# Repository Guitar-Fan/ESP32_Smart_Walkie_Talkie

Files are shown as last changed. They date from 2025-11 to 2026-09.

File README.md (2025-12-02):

# ESP32_Smart_Walkie_Talkie

This is a smart walkie talkie using an ESP32 development board. It functions as a walkie talkie. It uses a LoRa module to send radio signals 1 km+, and has smart features such as a low battery alert and a RSSI Signal Bar. The device features a custom-designed 3D-printed enclosure (made out of brown ABS filament) that houses all the electronics and provides a professional, handheld form factor.

I made this project to allow people to contact each other where cellular data wasn't an option. It would be especially helpful in a remote environment such as a forest, to talk with somebody, or broadcast your signal in case of emergencies. I wanted my first Blueprint project to be useful to the everyday public.

## Images

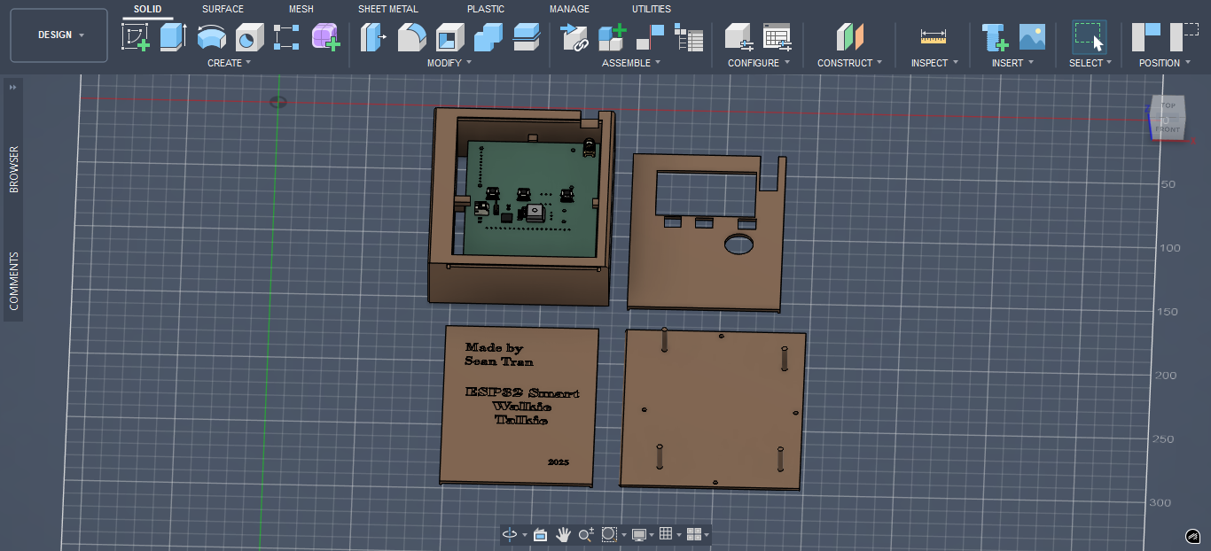
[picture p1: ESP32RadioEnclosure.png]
Enclosure View


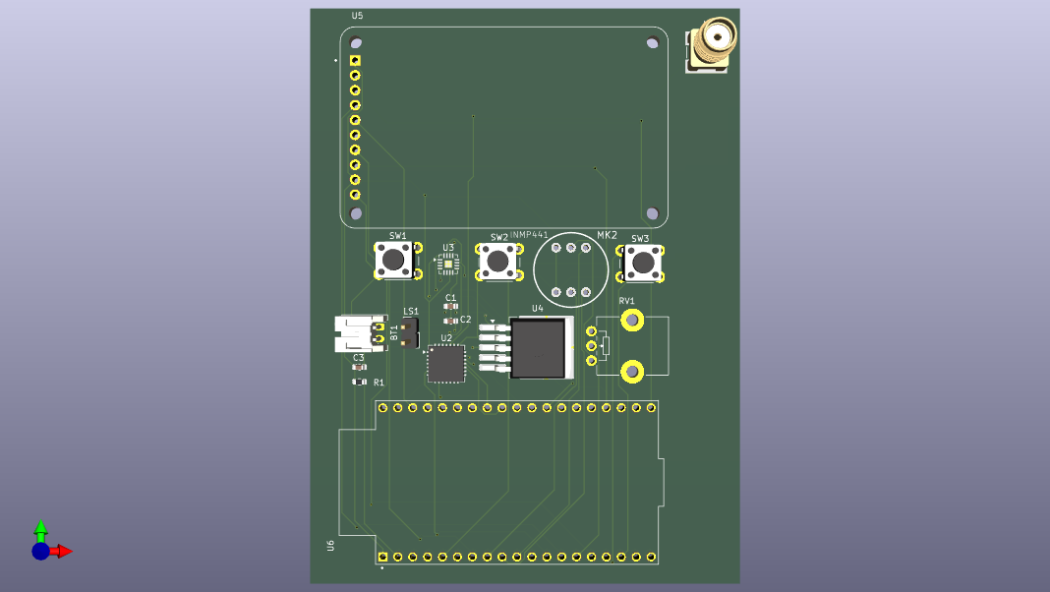
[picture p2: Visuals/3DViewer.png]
3D Viewer


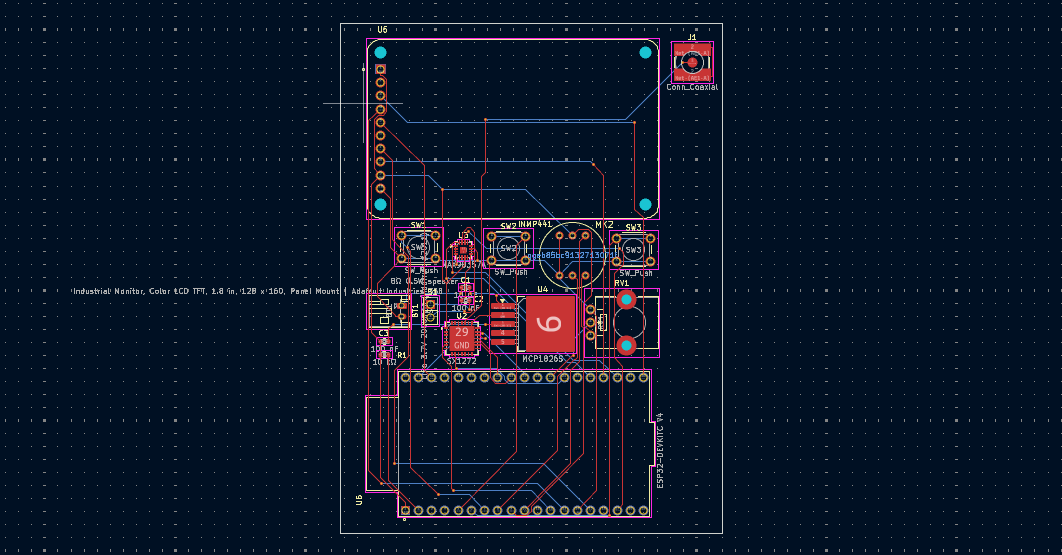
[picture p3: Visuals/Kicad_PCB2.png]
Kicad PCB


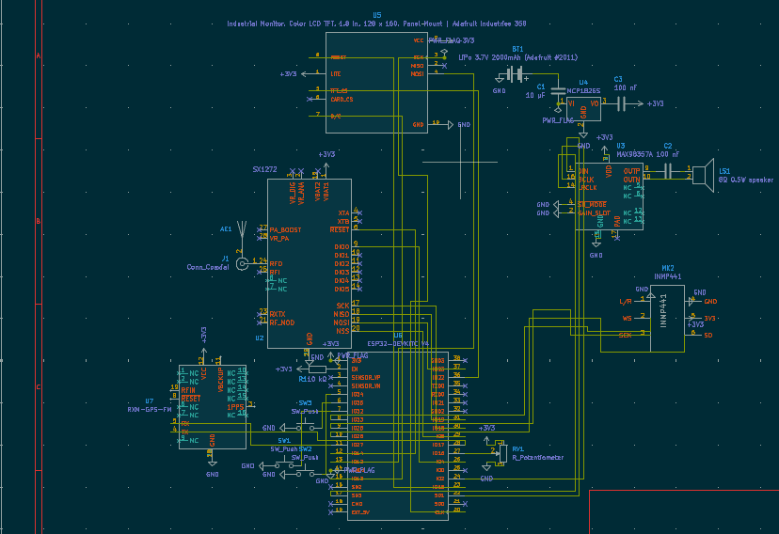
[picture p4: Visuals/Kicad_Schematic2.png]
Kicad Schematic


## Bill of Materials (BOM)

| Name | Qty | Description | Unit Price | Total Price | URL |
|---|-----|---|---|---|-----|
| 3.7V 103450 Polymer Lithium Battery, 2000 mAh Rechargeable | 2 | BATTERY LITH-ION 3.7V 2AH | $8.26 | $16.52 | [AliExpress](https://www.aliexpress.us/item/3256802548415679.html?gatewayAdapt=glo2usa4itemAdapt) |
| 1.8'' TFT Full Color LCD Display (2pcs) | 1 | TFT LCD display | $6.44 | $6.44 | [AliExpress](https://www.aliexpress.us/item/3256808787979678.html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) |
| Conn_Coaxial SMA KHD (5pcs) | 1 | Coaxial connector | $2.09 | $2.09 | [AliExpress](https://www.aliexpress.us/item/2255800008688086.html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) |
| MAX98357A | 2 | Audio amplifier | $1.93 | $3.86 | [AliExpress](https://www.aliexpress.us/item/3256805196806369.html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) |
| 3W 8 ohm 2W speaker | 2 | Audio output device | $2.03 | $4.06 | [AliExpress](https://www.aliexpress.us/item/3256805513567413.html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) |
| INMP441 | 2 | Omnidirectional microphone | $2.43 | $4.86 | [AliExpress](https://www.aliexpress.us/item/3256806131008765.html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) |
| ESP32-DEVKITC V4 | 2 | Microcontroller development board | $5.32 | $10.64 | [eBay](https://www.ebay.com/itm/376392617070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) |
| 915 MHz Meshtastic LoRa Antenna with RP or SMA Male 915MHz for LoRaWan Aerial | 2 | Antenna 915hz | $5.00 | $10.00 | [eBay](https://www.ebay.com/itm/154891841854) |
| [2-Pack] 3.7V USB Charger Cable SM-2P Plug Cable with LED Indicator | 1 | Recharging Unit for Battery | $3.98 | $3.98 | [Amazon](https://www.amazon.com/2-Pack-Charger-Indicator-Amphibious-Battery/dp/B0FF33J253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) |
| SX1272IMLTRT | 2 | LoRa transceiver module | $8.85 | $17.70 | [DigiKey](https://www.digikey.com/en/products/detail/semtech-corporation/SX1262IMLTRT/8564369) |
| JST_PH_S2B-PH-K_1x02_P2.00mm_Horizontal | 2 | Headers for 3.7v LiPo Batteries | $0.10 | $0.20 | [DigiKey](https://www.digikey.com/en/products/detail/jst-sales-america-inc/S2B-PH-K-S/926626) |
| MCP1826S-3302E/DB | 2 | Voltage regulator | $0.91 | $1.82 | [DigiKey](https://www.digikey.com/en/products/detail/microchip-technology/MCP1826S-3302E-DB/1635997) |
| R_Potentiometer 10K | 2 | Variable resistor | $0.89 | $1.78 | [DigiKey](https://www.digikey.com/en/products/detail/bourns-inc/PTV09A-4020F-B103/3534181) |
| PCB from PCBWay | 1 | PCB | $5.00 | $5.00 | - |
| KEMET CAP CER 0.1UF 50V X7R 0603 | 10 | 100 nF capacitors | $0.11 | $0.11 | [DigiKey](https://www.digikey.com/en/products/detail/kemet/C0603C104K5RACTU/1465594) |
| CAP CER 10UF 10V X5R 0603 (Samsung Electro-Mechanics) | 10 | 10 µF capacitors | $0.30 | $0.30 | [DigiKey](https://www.digikey.com/en/products/detail/samsung-electro-mechanics/CL10A106KP8NNNC/3886850) |
| YAGEO RES 10K OHM 1% 1/10W 0603 | 10 | 10k Resistor for pull-ups | $0.06 | $0.06 | [DigiKey](https://www.digikey.com/en/products/detail/yageo/RC0603FR-0710KL/726880) |
| CONN HEADER VERT 2POS 2.54MM | 2 | Speaker pin Header | $0.11 | $0.22 | [DigiKey](https://www.digikey.com/en/products/detail/samtec-inc/TSW-102-07-F-S/2685866) |
| SW_Push | 6 | Push button switch | Exclude | Exclude | Exclude |

Note: My build needs 2 of each component(s) to test

Note2: Capacitors and resistors cheaper to buy at 10 quantity than what needed

Total without Tax: $89.64  
Total Funding Needed: $111.42

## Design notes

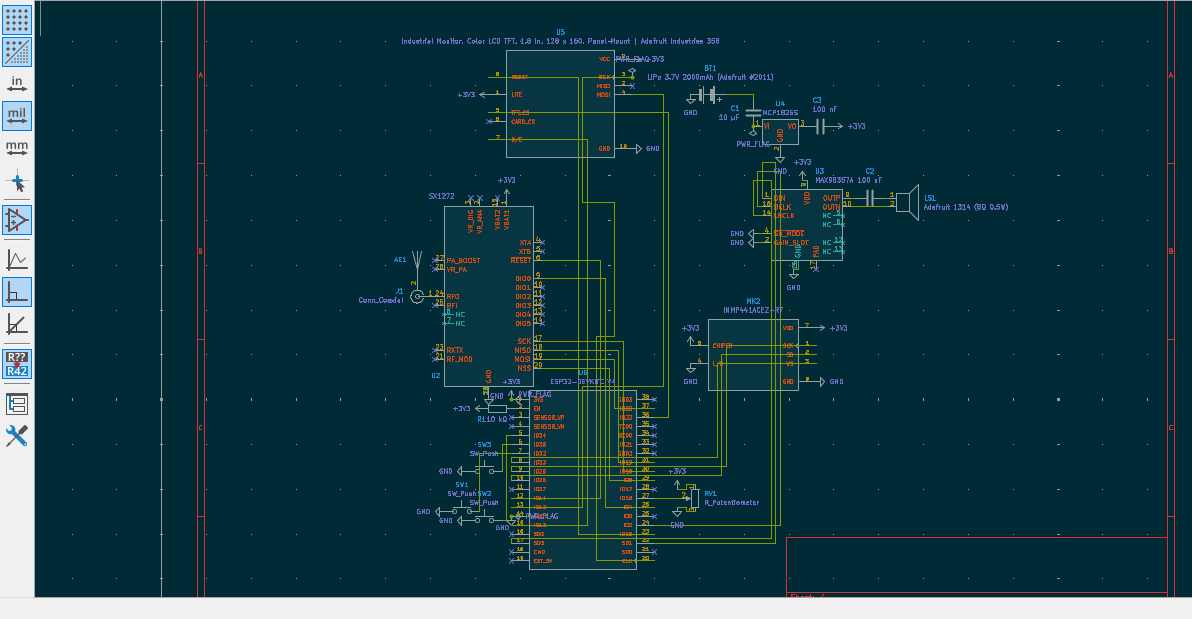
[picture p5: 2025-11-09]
Visuals/First_Draft/Kicad_Schematic.png

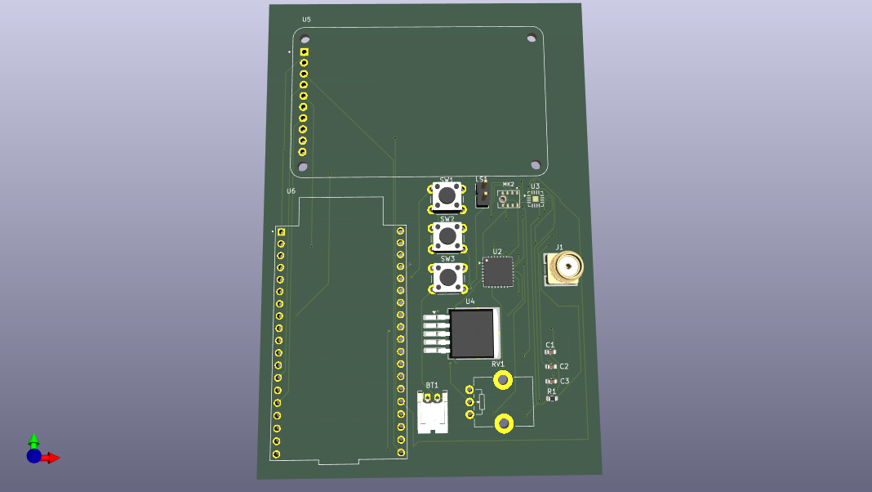
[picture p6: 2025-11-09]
Visuals/First_Draft/3DViewer_Kicad.png

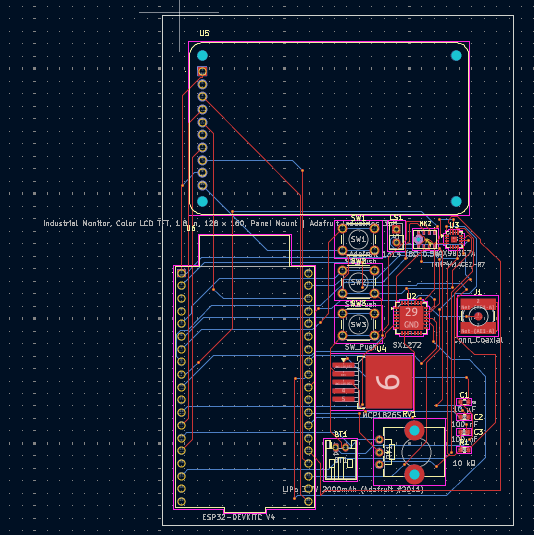
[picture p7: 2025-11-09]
Visuals/First_Draft/Kicad_PCB.png

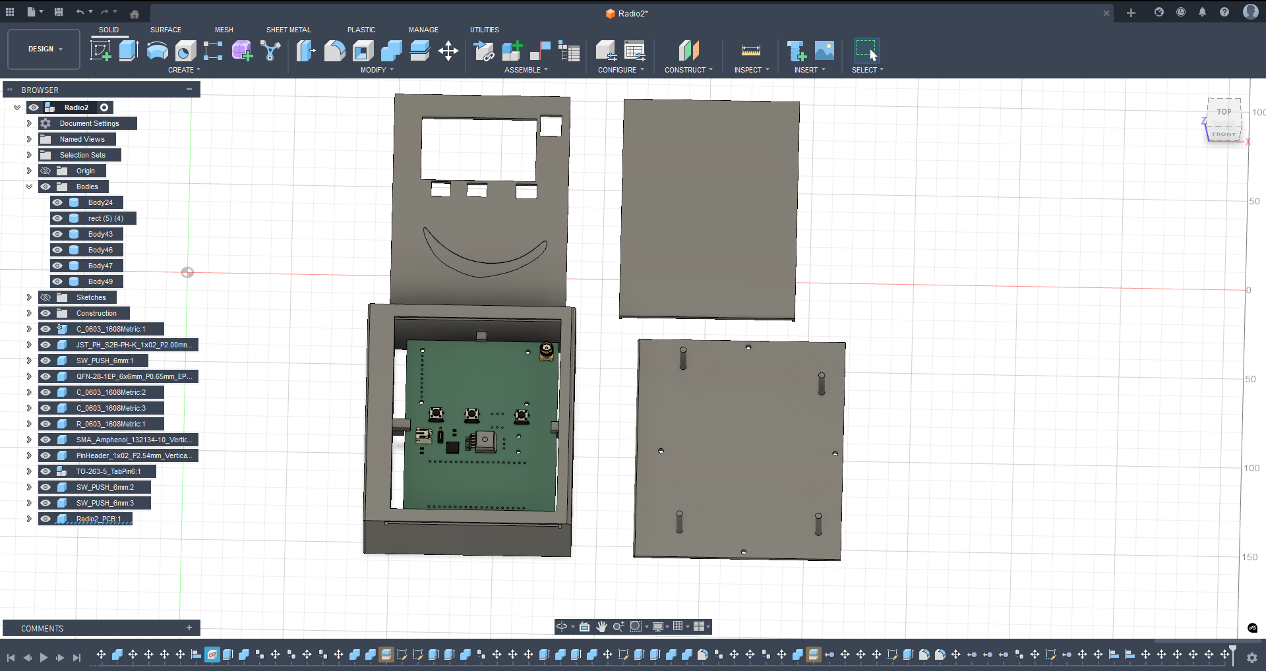
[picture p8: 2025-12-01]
Visuals/WalkieTalkieEnclosure_Fusion360.png

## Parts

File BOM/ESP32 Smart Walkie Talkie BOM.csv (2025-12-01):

Name | Qty | Description | Unit Price | Total Price | URL
3.7V 103450 Polymer Lithium Battery , 2000 mAh Rechargeable | 2 | BATTERY LITH-ION 3.7V 2AH | 8.26 | $16.52 | https://www.aliexpress.us/item/3256802548415679.html?gatewayAdapt=glo2usa4itemAdapt
1.8''tft Full Color Lcd Display (2pcs) | 1 | TFT LCD display | 6.44 | $6.44 | https://www.aliexpress.us/item/3256808787979678.html?curPageLogUid=IogOLCzfrTak
Conn_Coaxial SMA KHD (5pcs) | 1 | Coaxial connector | 2.09 | $2.09 | https://www.aliexpress.us/item/2255800008688086.html?curPageLogUid=HRgm0xYNEq4L |  | aliexpress: | 34.35
MAX98357A | 2 | Audio amplifier | $1.93 | $3.86 | https://www.aliexpress.us/item/3256805196806369.html?src=google |  | digikey: | 31.93
3w 8 ohm 2W speaker | 2 | Audio output device | 2.03 | $4.06 | https://www.aliexpress.us/item/3256805513567413.html?curPageLogUid=1UQMMRe9NU44 |  | Amazon: | 3.98
INMP441 | 2 | Omnidirectional microphone | 2.43 | $4.86 | https://www.aliexpress.us/item/3256806131008765.html?curPageLogUid=gpENJgXtYVrp |  | Ebay: | 33.8
ESP32-DEVKITC V4 | 2 | Microcontroller development board | $5.32 | $10.64 | https://www.ebay.com/itm/376392617070 |  | PCBWay: | $7.60
915 MHz Meshtastic LoRa Antenna with RP or SMA Male 915MHz for LoRaWan Aerial | 2 | Antenna 915hz | $5.00 | $10.00 | https://www.ebay.com/itm/154891841854 |  |  | 111.66
[2-Pack] 3.7V USB Charger Cable SM-2P Plug Cable with LED Indicator | 1 | Recharging Unit for Battery | 3.98 | $3.98 | https://www.amazon.com/2-Pack-Charger-Indicator-Amphibious-Battery/dp/B0FF33J253?rnid=386685011
SX1272IMLTRT | 2 | LoRa transceiver module | 8.85 | $17.70 | https://www.digikey.com/en/products/detail/semtech-corporation/SX1262IMLTRT/8564369
JST_PH_S2B-PH-K_1x02_P2.00mm_Horizontal | 2 | Headers for 3.7v LiPo Batteries | 0.1 | $0.20 | https://www.digikey.com/en/products/detail/jst-sales-america-inc/S2B-PH-K-S/926626
MCP1826S-3302E/DB | 2 | Voltage regulator | $0.91 | $1.82 | https://www.digikey.com/en/products/detail/microchip-technology/MCP1826S-3302E-DB/1635997
R_Potentiometer 10K | 2 | Variable resistor | 0.89 | $1.78 | https://www.digikey.com/en/products/detail/bourns-inc/PTV09A-4020F-B103/3534181
PCB from PCBWay | 1 | PCB | 5 | $5.00
KEMET CAP CER 0.1UF 50V X7R 0603 | 10 | 100 nF capacitors | 0.11 | $0.11 | https://www.digikey.com/en/products/detail/kemet/C0603C104K5RACTU/1465594
CAP CER 10UF 10V X5R 0603 (Samsung Electro-Mechanics) | 10 | 10 µF capacitors | $0.30 | $0.30 | https://www.digikey.com/en/products/detail/samsung-electro-mechanics/CL10A106KP8NNNC/3886850
YAGEO RES 10K OHM 1% 1/10W 0603 | 10 | 10k Resistor for pull-ups | $0.06 | $0.06 | https://www.digikey.com/en/products/detail/yageo/RC0603FR-0710KL/726880
CONN HEADER VERT 2POS 2.54MM | 2 | Speaker pin Header | 0.11 | $0.22 | https://www.digikey.com/en/products/detail/samtec-inc/TSW-102-07-F-S/2685866
SW_Push | 6 | Push button switch | Exclude | Exclude | Exclude
Note: My build needs 2 of each component(s) to test |  | Total without Tax: |  | $89.64 | Total Funding Needed: | $111.42
Note2: Capacitors and resistors cheaper to buy at 10 quantity than what needed

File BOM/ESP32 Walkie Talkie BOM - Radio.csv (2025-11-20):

Name | Qty | Description | Unit Price | Total Price | URL | Running Total
3.7V 103450 Polymer Lithium Battery , 2000 mAh Rechargeable | 1 | BATTERY LITH-ION 3.7V 2AH | 14 | $14.00 | https://www.aliexpress.us/item/3256802548415679.html?gatewayAdapt=glo2usa4itemAdapt | $20.29
1.8''tft Full Color Lcd Display (2pcs) | 1 | TFT LCD display | 6.44 | $6.44 | https://www.aliexpress.us/item/3256808787979678.html?curPageLogUid=IogOLCzfrTak | $8.53
Conn_Coaxial SMA KHD (5pcs) | 1 | Coaxial connector | 2.09 | $2.09 | https://www.aliexpress.us/item/2255800008688086.html?curPageLogUid=HRgm0xYNEq4L | 4.18 | aliexpress: | 38.92
MAX98357A | 2 | Audio amplifier | $1.93 | $3.86 | https://www.aliexpress.us/item/3256805196806369.html?src=google | 6.74 | digikey: | 31.83
3w 8 ohm 2W speaker | 2 | Audio output device | 2.03 | $4.06 | https://www.aliexpress.us/item/3256805513567413.html?curPageLogUid=1UQMMRe9NU44 | 6.56 | Amazon: | 12.12
INMP441 | 2 | Omnidirectional microphone | 2.43 | $4.86 | https://www.aliexpress.us/item/3256806131008765.html?curPageLogUid=gpENJgXtYVrp | 7.36 | Ebay: | 33.8
ESP32-DEVKITC V4 | 2 | Microcontroller development board | $5.32 | $10.64 | https://www.ebay.com/itm/376392617070 | 16.61 | PCBWay: | $7.60
915 MHz Meshtastic LoRa Antenna with RP or SMA Male 915MHz for LoRaWan Aerial | 2 | Antenna 915hz | $5.00 | $10.00 | https://www.ebay.com/itm/154891841854 | 15.15 |  | 124.27
[2-Pack] 3.7V USB Charger Cable SM-2P Plug Cable with LED Indicator | 1 | Recharging Unit for Battery | 3.98 | $3.98 | https://www.amazon.com/2-Pack-Charger-Indicator-Amphibious-Battery/dp/B0FF33J253?rnid=386685011 | 3.98
200PCS Electrolytic Capacitor Kit | 1 | Need 10 µF capacitors (2) & 100 nF capacitors (4) | 6.99 | $6.99 | https://www.amazon.com/200PCS-Electrolytic-Capacitor-Kit-Electronics/dp/B0FH1R7N94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 | 7.72
SX1272IMLTRT | 2 | LoRa transceiver module | 8.85 | $17.70 | https://www.digikey.com/en/products/detail/semtech-corporation/SX1272IMLTRT/4259549 | 17.7
JST_PH_S2B-PH-K_1x02_P2.00mm_Horizontal | 10 | Headers for 3.7v LiPo Batteries | 0.1 | $1.00 | https://www.digikey.com/en/products/detail/jst-sales-america-inc/S2B-PH-K-S/926626 | $1.00
MCP1826S-3302E/DB | 2 | Voltage regulator | $0.91 | $1.82 | https://www.digikey.com/en/products/detail/microchip-technology/MCP1826S-3302E-DB/1635997 | 1.82
R_Potentiometer 10K | 2 | Variable resistor | 0.89 | $1.78 | https://www.digikey.com/en/products/detail/bourns-inc/PTV09A-4020F-B103/3534181 | 1.78
PCB from PCBWay | 1 | PCB | 5 | $5.00 |  | $7.60
SW_Push | 6 | Push button switch | Exclude | Exclude | Exclude | Exclude
10 k resistor | 2 | Resistor for pull-ups | Exclude | Exclude | Exclude | Exclude
 |  | Total without Tax: |  | $58.91 | Total Funding Needed: | 124.27

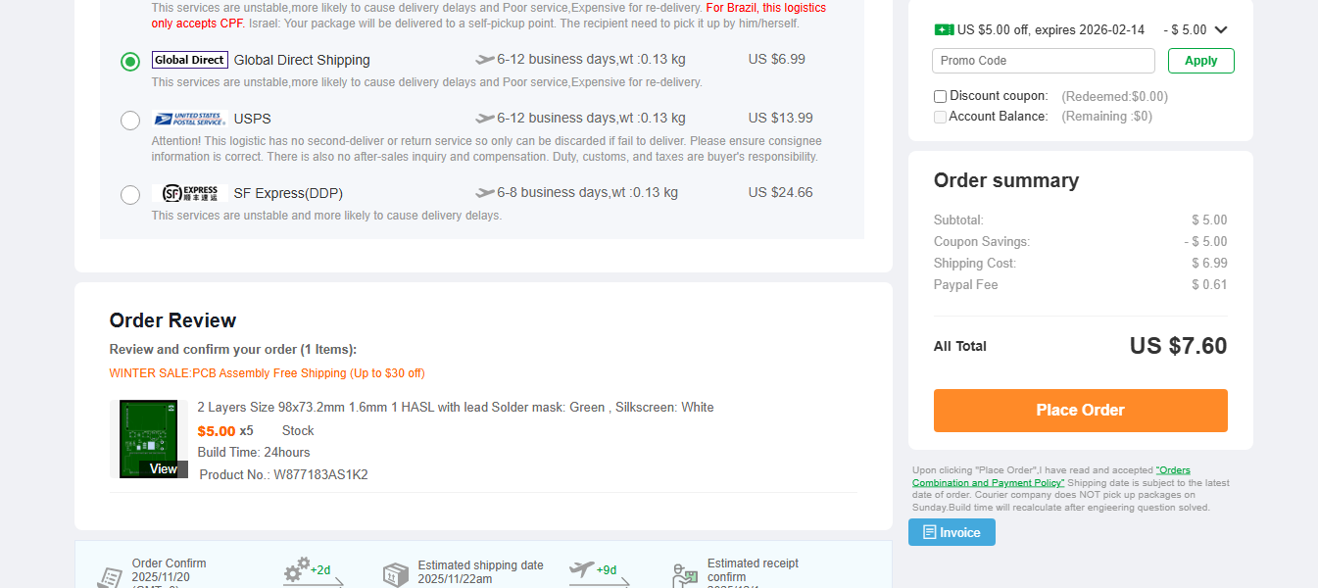
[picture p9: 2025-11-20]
PCBWayOrder.png

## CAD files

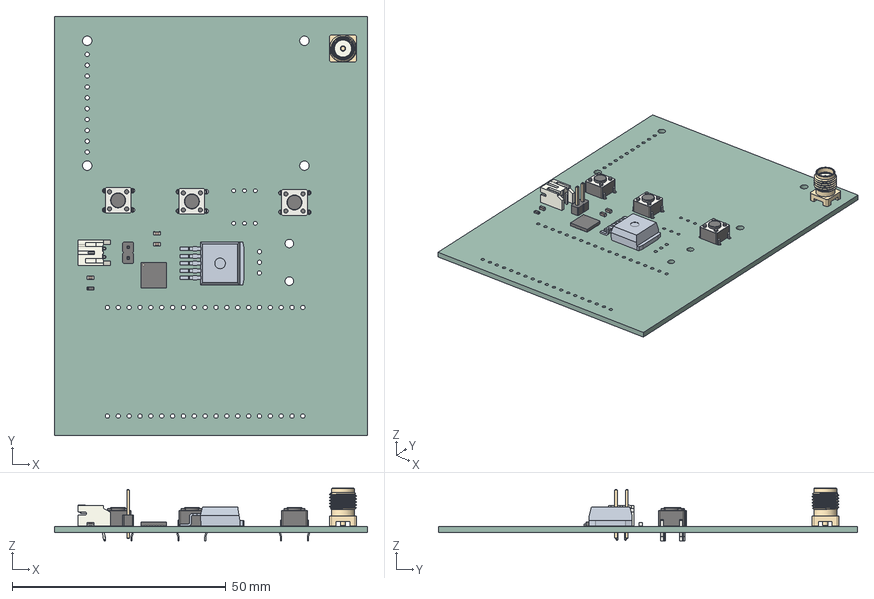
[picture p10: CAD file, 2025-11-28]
Radio2.step
73.2 x 98.0 x 12.3 mm
C_0603_1608Metric x 3
JST_PH_S2B-PH-K_1x02_P2.00mm_Horizontal
SW_PUSH_6mm x 3
QFN-28-1EP_6x6mm_P0.65mm_EP4.8x4.8mm
R_0603_1608Metric
SMA_Amphenol_132134-10_Vertical
PinHeader_1x02_P2.54mm_Vertical
Radio2 1.10.1
Radio2_PCB

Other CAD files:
Visuals/First_Draft/Radio.stl

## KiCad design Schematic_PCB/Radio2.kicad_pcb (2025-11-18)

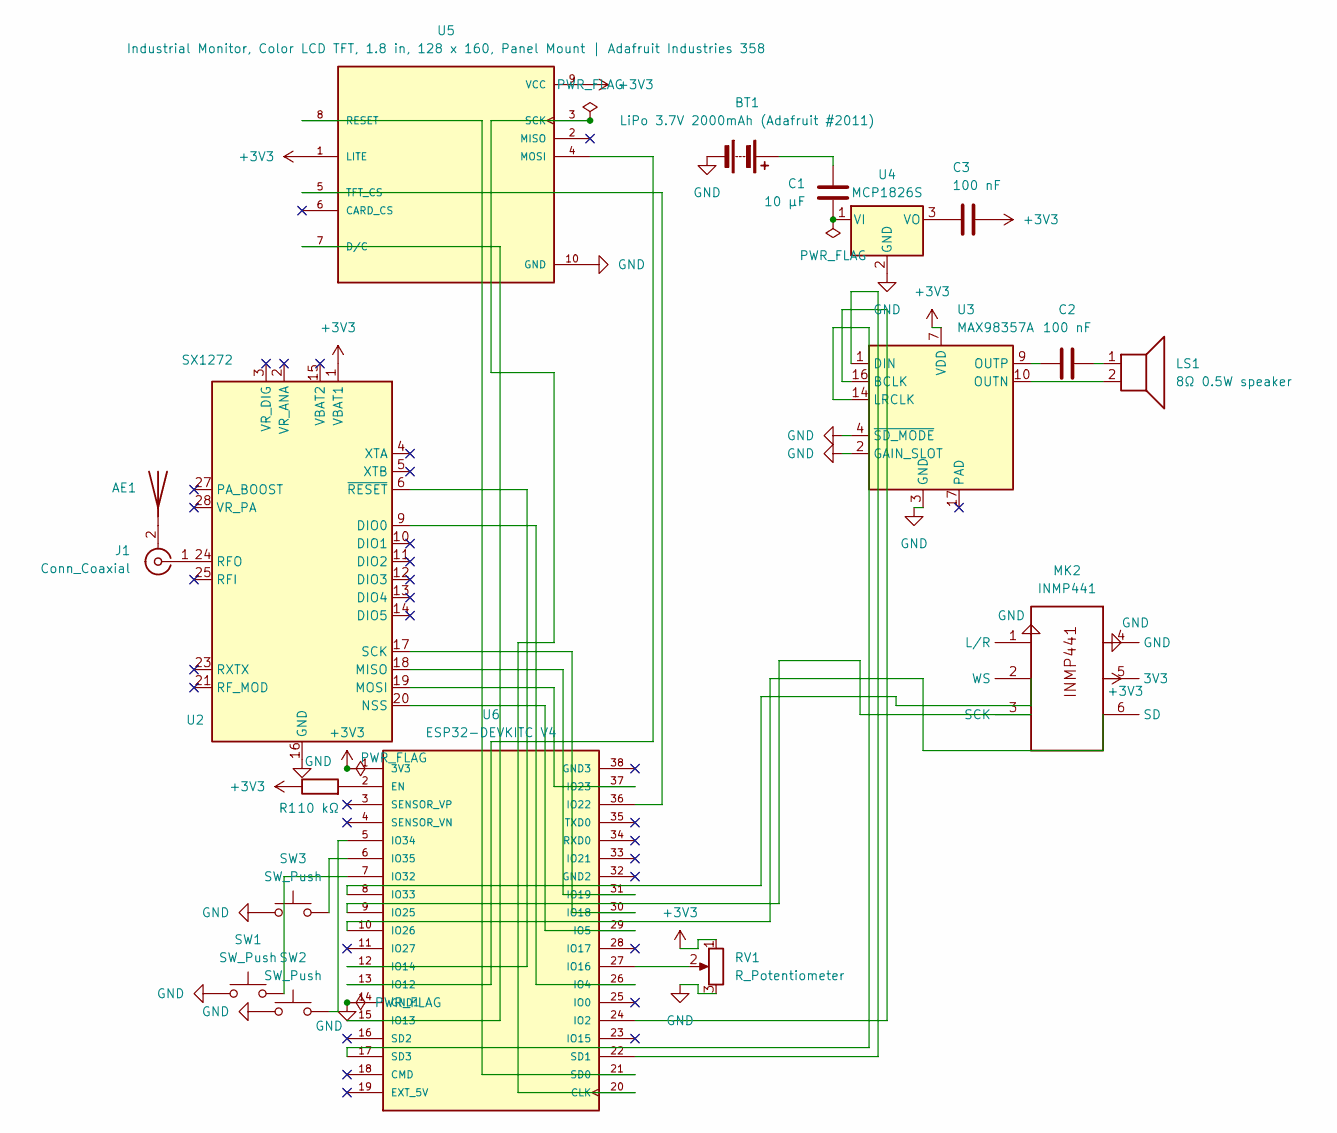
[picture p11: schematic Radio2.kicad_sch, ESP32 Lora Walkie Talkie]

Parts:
AE1: Antenna
BT1: LiPo 3.7V 2000mAh (Adafruit #2011); JST_PH_S2B-PH-K_1x02_P2.00mm_Horizontal
C1: 10 µF; C_0603_1608Metric
C2, C3: 100 nF; C_0603_1608Metric
J1: Conn_Coaxial; SMA_Amphenol_132134-10_Vertical
LS1: 8Ω 0.5W speaker; PinHeader_1x02_P2.54mm_Vertical
MK2: INMP441
R1: 10 kΩ; R_0603_1608Metric
RV1: R_Potentiometer; Potentiometer_Bourns_PTV09A-1_Single_Vertical
SW1, SW2, SW3: SW_Push; SW_PUSH_6mm
U2: SX1272; QFN-28-1EP_6x6mm_P0.65mm_EP4.8x4.8mm
U3: MAX98357A; TQFN-16-1EP_3x3mm_P0.5mm_EP1.23x1.23mm
U4: MCP1826S; TO-263-5_TabPin6
U5: Industrial Monitor, Color LCD TFT, 1.8 in, 128 x 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; MODULE_358; PARTREV 2021-12-09
U6: ESP32-DEVKITC V4; MODULE_ESP32-DEVKITC; PARTREV N/A

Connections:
+3V3: C3.1, MK2.5 (3V3), R1.1, RV1.1, U2.1 (VBAT1), U3.7 (VDD), U3.8 (VDD), U5.1 (LITE), U5.9 (VCC), U6.1 (3V3)
GND: BT1.2 (-), MK2.1 (L/R), MK2.4 (GND), RV1.3, SW1.2, SW2.2, SW3.2, U2.16 (GND), U2.22 (GND), U2.26 (GND), U2.29 (GND), U3.2 (GAIN_SLOT), U3.3 (GND), U3.4 (~SD_MODE), U3.11 (GND), U3.15 (GND), U4.2 (GND), U5.10 (GND), U6.14 (GND1)
unnamed: AE1.1, J1.2 (Ext)
unnamed: BT1.1 (+), C1.1
unnamed: C2.2, LS1.1
unnamed: J1.1 (In), U2.24 (RFO)
unnamed: MK2.3 (SCK), U6.9 (IO25)
unnamed: MK2.6 (SD), U6.10 (IO26)
unnamed: MK2.2 (WS), U6.8 (IO33)
unnamed: U2.9 (DIO0), U6.26 (IO4)
unnamed: U2.18 (MISO), U6.31 (IO19)
unnamed: U2.19 (MOSI), U6.37 (IO23)
unnamed: U2.20 (NSS), U6.29 (IO5)
unnamed: U2.17 (SCK), U6.30 (IO18)
unnamed: U2.6 (~RESET), U6.12 (IO14)
unnamed: U3.16 (BCLK), U6.24 (IO2)
unnamed: U3.1 (DIN), U6.22 (SD1)
unnamed: U3.14 (LRCLK), U6.17 (SD3)
unnamed: LS1.2, U3.10 (OUTN)
unnamed: C2.1, U3.9 (OUTP)
unnamed: C1.2, U4.1 (VI)
unnamed: C3.2, U4.3 (VO)
unnamed: U5.7 (D/C), U6.15 (IO13)
unnamed: U5.4 (MOSI), U6.13 (IO12)
unnamed: U5.3 (SCK), U6.20 (CLK)
unnamed: U5.5 (TFT_CS), U6.36 (IO22)
unnamed: R1.2, U6.2 (EN)
unnamed: RV1.2, U6.27 (IO16)
unnamed: SW1.1, U6.7 (IO32)
unnamed: SW2.1, U6.5 (IO34)
unnamed: SW3.1, U6.6 (IO35)

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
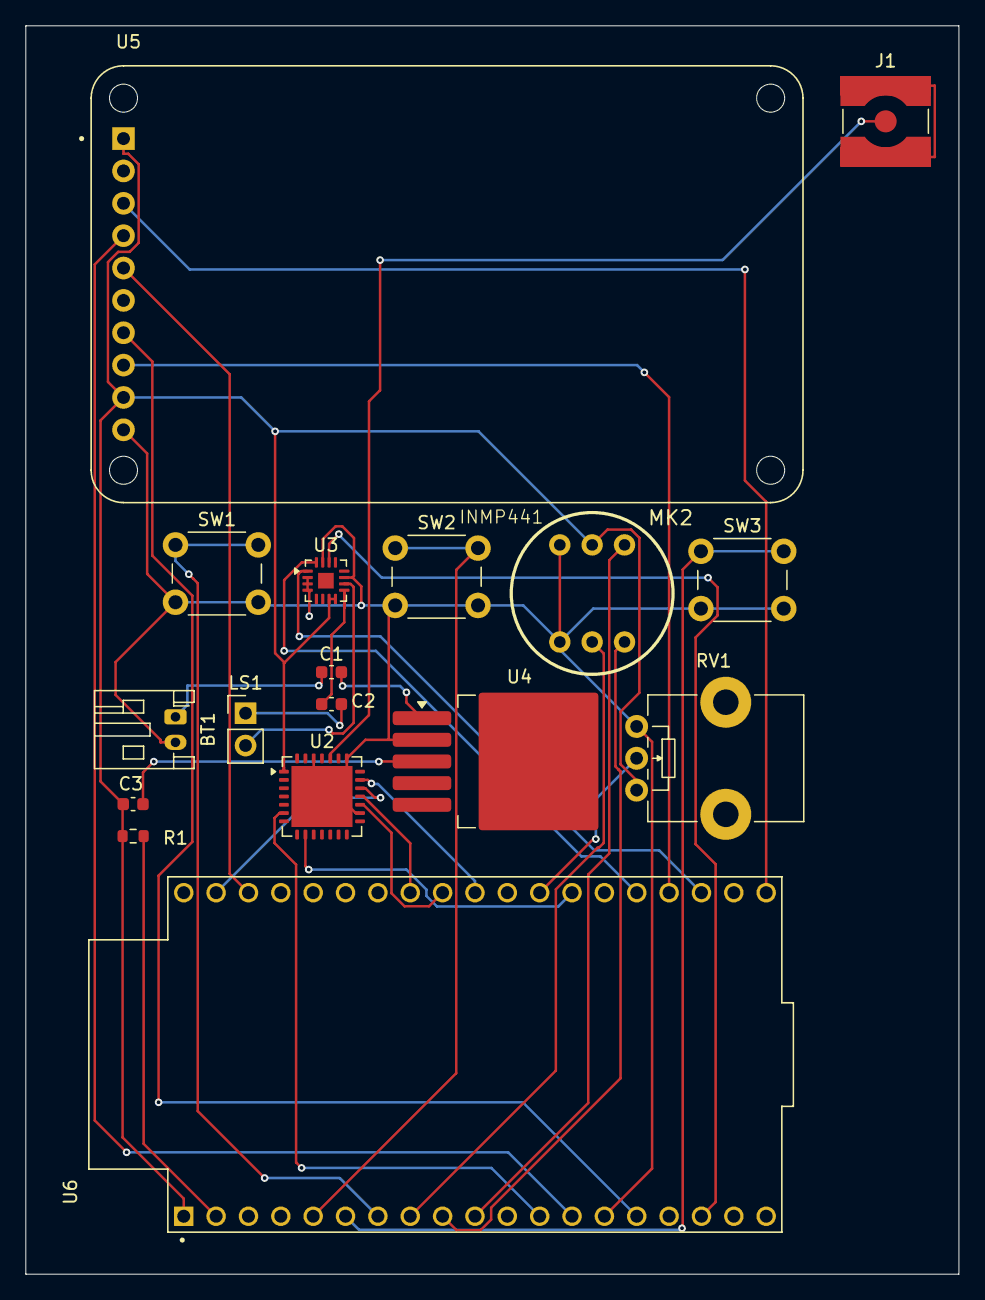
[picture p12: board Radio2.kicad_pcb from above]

Board: 2 copper layers, 73.2 x 98.0 mm, 17 parts (0 on the bottom side), 31 nets.

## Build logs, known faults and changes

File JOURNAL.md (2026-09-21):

<!--
  This journal is auto generated by Stasis.
-->

# 12/2/2025 2 AM - Slightly modified enclosure

_Time spent: 1h_

ESP32RadioEnclosure
I forgot to leave a hole for the potentiometer. Also I adjusted the antenna hole to be for a right-angled antenna. The sliding lid dimensions were too tight, so I adjusted that as well. I ended with adding my name, the year and the name of the project onto the separate dust lid.



# 12/1/2025 2 AM - Designed and finished enclosure in Fusion 360

_Time spent: 4h_

I finished designing the enclosure in Fusion 360. I kept brainstorming and modifying the design to allow for the enclosure to be taken apart. I was considering going for a no-screw build after making the top lid able to slid in, but I decided against it for time-saving. I chose the material to be brown ABS filament.ESP32RadioEnclosureTopViewESP32RadioEnclosureDiagonalView

ESP32RadioEnclosureDiagonalView

# 11/20/2025 4 AM - SHOPPING IS VERY STRESSFUL. Also coded firmware

_Time spent: 1h_

Shopping for my components was time consuming, especially trying to find reasonably priced items from legitimate websites and vendors. But I finally finished shopping. I was surprised how hard it was to find a cheap antenna for my walkie talkie. I tried to put some cool features into the firmware, such as texting. I think I'm finally ready to ship.



# 11/18/2025 3 PM - Fixed PCB, tested order process from PCB manufacturers

_Time spent: 1h_

Had to fix PCB again, by orienting the battery JST connector the 180 degrees, so that the speaker pins wouldn't block the battery connection. I exported my project as Gerber files and put the Gerbers into PCBWay and JCLPCB to compare price. PCBWay was cheaper, so I put the Gerber file into the shopping cart to have PCBWay review for printing. It got rejected because I didn't put the drill files into the Gerber zip. So I did that, and it went through. PCBWayOrderRadio



# 11/15/2025 1 AM - Chose more available microphone, adjusted layout of PCB

_Time spent: 1h_

I started on the BOM, first shopped my components at reputable sites like amazon, ebay. When I was done getting all the links, the total was about $130 without tax. For what I'm doing, that is EXPENSIVE. So I chose links from Aliexpress, which reduced my total to about $70. I couldn't find a INMP441ACEZ-R7, which was actually obsolete, so to INMP441 omnidirectional microphone. Lesson on checking if parts are available. Also my last PCB design, the layout was ridiculous, mostly the buttons. So I fixed that.



# 11/7/2025 2 AM - Finished PCB

_Time spent: 0.5h_

I fixed the errors in the DRC like reference text cutting off silkscreen of capacitor 2 and 3. I just need to organize the files and journaling and ship.
Radio

Radio

# 11/5/2025 4 AM - Finished schematic 2nd draft, almost finished PCB wiring

_Time spent: 2h_


[image](/user-attachments/blobs/proxy/eyJfcmFpbHMiOnsiZGF0YSI6ODQ5NywicHVyIjoiYmxvYl9pZCJ9fQ==--1caf3da2455996e0cd85523d267ac2e2f79baac9/image.png)
I completed the schematic, and went on to do the PCB wiring and arrangement. It felt like a puzzle, trying to wire pins while dodging other wires and changing color or wire. I used the Freerouting plugin to start me up, then wired the unconnected pins. I have 2 left. (Sorry wrong image uploaded)



# 11/2/2025 11 PM - Forgot to add a screen and a flashable ESP32 dev board

_Time spent: 1h_

I was working on the PCB for the radio, because I thought I finished the schematic, using the Freerouting plugin to auto route the connections, when it occurred to me that the ESP32 model I chose didn't have a USB-C port, therefore it wasn't reprogrammable. I also added a LCD color screen. I'm considering switching to EasyEDA for finding models of components easier.



# 11/1/2025 3 AM - Implemented power system, learned about Kicad Plugins

_Time spent: 1.5h_

I worked on adding footprints for my components and implemented a power system. I decided to use those AA rechargeable batteries that can be recharged using USB C. I learned about Interactive Html BOM plugin and generated a sample BOM, after updating the unfinished schematic to my pcb file.



# 10/28/2025 2 PM - Finished 1st draft of schematic.

_Time spent: 2h_

Since I'm a complete beginner at designing schematics in KicadRadio3
, I choose an easier project then the Frequency Generator for Healing that is practical and useful. I finished the schematic, learned about the EFC Checker, got 47 errors of unconnected pins, put X symbols over them, left with 2 errors of "input pins not driven by output power pins", put PWR Flags over the error pins, got zero errors with EFC.



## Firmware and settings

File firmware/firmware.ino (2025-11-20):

#include <LoRa.h>
#include <SPI.h>
#include <Adafruit_GFX.h>
#include <Adafruit_ST7735.h>
#include <driver/i2s.h>

// === PINS ===
#define LORA_NSS    5
#define LORA_SCK   18
#define LORA_MOSI  23
#define LORA_MISO  19
#define LORA_DIO0  26
#define LORA_RST   14

#define I2S_BCLK    4
#define I2S_WS     25
#define I2S_DIN    33   // Speaker OUT
#define I2S_DOUT   32   // Mic IN

#define TFT_CS     13
#define TFT_DC     12
#define TFT_RST    27

#define PTT_PIN     1   // TX pin

// === TEXT MODE BUTTONS ===
#define BTN_TEXT    0   // GPIO0 (BOOT button) - Enter text mode
#define BTN_UP     35
#define BTN_DOWN   36
#define BTN_LEFT   39
#define BTN_RIGHT  34

// === OBJECTS ===
Adafruit_ST7735 tft = Adafruit_ST7735(TFT_CS, TFT_DC, TFT_RST);

// === I2S ===
#define I2S_NUM     I2S_NUM_0
#define SAMPLE_RATE 16000
#define BUFFER_LEN  512
int16_t audioBuffer[BUFFER_LEN];

// === STATE ===
bool transmitting = false;
bool receiving = false;
int rssi = 0;
unsigned long lastMicCheck = 0;
const int MIC_THRESHOLD = 900;

// === TEXT MODE ===
bool textMode = false;
bool typing = false;
String currentMessage = "";
String lastReceivedText = "";

const char keyboard[4][11] = {
  "abcdeABCDE",
  "fghijFGHIJ",
  "klmnoKLMNO",
  "pqrstPQRSTuvwxy z01234 56789.!?,"
};
int cursorX = 0, cursorY = 0;

void setup() {
  Serial.begin(115200);
  pinMode(PTT_PIN, INPUT_PULLUP);
  pinMode(BTN_TEXT, INPUT_PULLUP);
  pinMode(BTN_UP, INPUT_PULLUP);
  pinMode(BTN_DOWN, INPUT_PULLUP);
  pinMode(BTN_LEFT, INPUT_PULLUP);
  pinMode(BTN_RIGHT, INPUT_PULLUP);

  // --- TFT ---
  tft.initR(INITR_BLACKTAB);
  tft.setRotation(1);
  tft.fillScreen(ST7735_BLACK);
  tft.setTextSize(2);
  tft.setTextColor(ST7735_CYAN);
  tft.setCursor(10, 20);
  tft.println("SMART");
  tft.setTextSize(1);
  tft.setCursor(10, 50);
  tft.println("Walkie-Talkie + TEXT v2.0");
  delay(2000);

  // --- LoRa ---
  LoRa.setPins(LORA_NSS, LORA_RST, LORA_DIO0);
  if (!LoRa.begin(915E6)) {
    tft.fillScreen(ST7735_RED);
    tft.setCursor(10, 50);
    tft.println("LoRa FAILED");
    while (1);
  }
  LoRa.setSpreadingFactor(12);
  LoRa.setSignalBandwidth(125E3);
  LoRa.setTxPower(20);
  LoRa.receive(); // Always listening

  // --- I2S ---
  i2s_config_t i2s_config = {
    .mode = (i2s_mode_t)(I2S_MODE_MASTER | I2S_MODE_RX | I2S_MODE_TX),
    .sample_rate = SAMPLE_RATE,
    .bits_per_sample = I2S_BITS_PER_SAMPLE_16BIT,
    .channel_format = I2S_CHANNEL_FMT_ONLY_LEFT,
    .communication_format = I2S_COMM_FORMAT_STAND_I2S,
    .intr_alloc_flags = 0,
    .dma_buf_count = 8,
    .dma_buf_len = 64
  };
  i2s_pin_config_t pin_config = {
    .bck_io_num = I2S_BCLK,
    .ws_io_num = I2S_WS,
    .data_out_num = I2S_DIN,
    .data_in_num = I2S_DOUT
  };
  i2s_driver_install(I2S_NUM, &i2s_config, 0, NULL);
  i2s_set_pin(I2S_NUM, &pin_config);

  tft.fillScreen(ST7735_BLACK);
  tft.setTextColor(ST7735_GREEN);
  tft.println("LoRa + TEXT READY");
  delay(1000);
  tft.fillScreen(ST7735_BLACK);
}

void loop() {
  handleButtons();
  handlePTT();
  handleAutoSquelch();
  handleReceive();
  updateDisplay();
  delay(50);
}

void handleButtons() {
  if (digitalRead(BTN_TEXT) == LOW) {
    delay(200);
    if (!textMode) enterTextMode();
    else exitTextMode();
  }

  if (typing) {
    if (digitalRead(BTN_UP) == LOW)    { cursorY = max(0, cursorY - 1); delay(200); }
    if (digitalRead(BTN_DOWN) == LOW)  { cursorY = min(3, cursorY + 1); delay(200); }
    if (digitalRead(BTN_LEFT) == LOW)  { cursorX = max(0, cursorX - 1); delay(200); }
    if (digitalRead(BTN_RIGHT) == LOW) { cursorX = min(9, cursorX + 1); delay(200); }

    // Select character (hold TEXT + press direction to send)
    static unsigned long selectPress = 0;
    if (digitalRead(BTN_TEXT) == LOW && typing) {
      if (millis() - selectPress > 500) {
        char c = keyboard[cursorY][cursorX];
        if (c != ' ') {
          if (c >= 'a' && c <= 'z' && bitRead(cursorX, 0)) c -= 32; // crude shift
          currentMessage += c;
        } else if (currentMessage.length() > 0) {
          currentMessage.remove(currentMessage.length() - 1); // backspace
        }
        selectPress = millis();
      }
    }

    // Send message: double-tap TEXT button
    static bool lastTextState = HIGH;
    bool curr = digitalRead(BTN_TEXT);
    if (lastTextState == LOW && curr == HIGH && currentMessage.length() > 0 && typing) {
      static unsigned long lastTap = 0;
      if (millis() - lastTap < 400) {
        sendTextMessage(currentMessage);
        currentMessage = "";
        beep(1000, 100);
      }
      lastTap = millis();
    }
    lastTextState = curr;
  }
}

void enterTextMode() {
  textMode = true;
  typing = true;
  currentMessage = "";
  cursorX = cursorY = 0;
  beep(800, 80);
}

void exitTextMode() {
  textMode = false;
  typing = false;
  currentMessage = "";
  beep(600, 80);
}

void sendTextMessage(String msg) {
  LoRa.beginPacket();
  LoRa.write(0x02); // Text packet
  LoRa.print(msg);
  LoRa.endPacket();
  lastReceivedText = "You: " + msg; // show your own message
}

void handlePTT() {
  if (textMode) return; // disable voice when typing
  bool ptt = digitalRead(PTT_PIN) == LOW;
  if (ptt && !transmitting) startTransmit();
  else if (!ptt && transmitting) stopTransmit();
}

void handleAutoSquelch() {
  if (textMode || transmitting) return;
  if (millis() - lastMicCheck > 50) {
    if (micLevel() > MIC_THRESHOLD) {
      startTransmit();
    }
    lastMicCheck = millis();
  }
}

void startTransmit() {
  if (textMode) return;
  transmitting = true;
  LoRa.beginPacket();
  LoRa.write(0x01); // Audio packet header
}

void stopTransmit() {
  if (transmitting) {
    LoRa.endPacket();
    transmitting = false;
  }
}

void handleReceive() {
  int packetSize = LoRa.parsePacket();
  if (packetSize) {
    uint8_t type = LoRa.read();
    rssi = LoRa.packetRssi();

    if (type == 0x01) { // Audio
      receiving = true;
      while (LoRa.available() >= 2) {
        uint8_t high = LoRa.read();
        uint8_t low = LoRa.read();
        int16_t sample = (high << 8) | low;
        i2s_write_bytes(I2S_NUM, (const char*)&sample, 2, 0);
      }
      receiving = false;

    } else if (type == 0x02) { // Text
      String text = LoRa.readString();
      lastReceivedText = text;
      beep(1200, 150);
      beep(800, 100);
    }
  }
}

int micLevel() {
  size_t bytesRead = 0;
  i2s_read(I2S_NUM, audioBuffer, BUFFER_LEN * 2, &bytesRead, 0);
  if (bytesRead == 0) return 0;
  long sum = 0;
  for (int i = 0; i < BUFFER_LEN; i++) sum += abs(audioBuffer[i]);
  return sum / BUFFER_LEN;
}

void beep(int freq, int dur) {
  tone(33, freq, dur); // simple tone on speaker pin (works on most amps)
}

void drawKeyboard() {
  tft.fillRect(0, 40, 160, 80, ST7735_BLACK);
  tft.setTextSize(1);
  for (int y = 0; y < 4; y++) {
    for (int x = 0; x < 10; x++) {
      uint16_t color = (x == cursorX && y == cursorY) ? ST7735_YELLOW : ST7735_WHITE;
      tft.setTextColor(color);
      tft.setCursor(5 + x*15, 45 + y*18);
      char c = keyboard[y][x];
      tft.print(c == ' ' ? '_' : c);
    }
  }
  tft.setTextColor(ST7735_CYAN);
  tft.setCursor(0, 120);
  tft.fillRect(0, 120, 160, 8, ST7735_BLACK);
  tft.print(currentMessage + "_");
}

void updateDisplay() {
  tft.fillScreen(ST7735_BLACK);

  // Title
  tft.setTextSize(2);
  tft.setTextColor(ST7735_CYAN);
  tft.setCursor(20, 5);
  tft.println("SMART");

  if (textMode) {
    tft.setTextSize(1);
    tft.setTextColor(ST7735_MAGENTA);
    tft.setCursor(5, 25);
    tft.print("TEXT MODE");
    drawKeyboard();

    if (lastReceivedText != "") {
      tft.setTextColor(ST7735_YELLOW);
      tft.setCursor(0, 30);
      tft.print(lastReceivedText);
    }
    return;
  }

  // Normal voice mode
  tft.setTextSize(1);
  tft.setTextColor(transmitting ? ST7735_RED : ST7735_GREEN);
  tft.setCursor(5, 30);
  tft.print(transmitting ? "TX VOICE" : "RX READY");
  if (receiving) {
    tft.setTextColor(ST7735_YELLOW);
    tft.print(" PLAYING");
  }

  // Show last text message
  if (lastReceivedText != "") {
    tft.setTextColor(ST7735_YELLOW);
    tft.setCursor(0, 45);
    tft.print("MSG: ");
    tft.print(lastReceivedText.substring(0, 20));
  }

  // RSSI
  tft.setCursor(5, 70);
  tft.setTextColor(ST7735_WHITE);
  tft.print("RSSI: "); tft.print(rssi); tft.print(" dBm");
  int bar = map(constrain(rssi, -120, -50), -120, -50, 0, 100);
  tft.fillRect(5, 85, bar, 8, ST7735_GREEN);

  // Mic + Batt
  int mic = micLevel();
  int micBar = map(constrain(mic, 0, 2000), 0, 2000, 0, 100);
  tft.setCursor(5, 100);
  tft.print("Mic: "); tft.print(mic);
  tft.fillRect(5, 115, micBar, 8, ST7735_BLUE);

  int batt = analogRead(34);
  int pct = map(constrain(batt, 1800, 2300), 1800, 2300, 0, 100);
  pct = constrain(pct, 0, 100);
  tft.setCursor(5, 130);
  tft.print("Batt: "); tft.print(pct); tft.print("%");
}

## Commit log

2025-11-10 gerber files
    [Radio-B_Cu.gbr, Radio-B_Mask.gbr, Radio-B_Paste.gbr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]
2025-11-15 upload radio2
    [Radio-B_Cu.gbr, Radio-B_Mask.gbr, Radio-B_Paste.gbr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]
2025-11-18 upload new files
    [Radio2-B_Cu.gbr, Radio2-B_Mask.gbr, Radio2-B_Paste.gbr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]
2025-11-20 bom fix
    [ESP32 Walkie Talkie BOM - Radio (1).csv]
2025-11-21 bom and 3d viewer
2025-11-24 bom update
    [ESP32 Walkie Talkie BOM - Radio (3).csv]
2025-11-28 step and 3dviewer update
    [Radio2.step, Radio2.stl]
2025-12-01 enclosure and bom update
    [ESP32 Walkie Talkie BOM - Radio (3).csv, ESP32 Walkie Talkie BOM - Radio (5).csv, ESP32WalkieTalkieEnclosure.3mf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]
2025-12-02 update enclosure
    [ESP32WalkieTalkieEnclosure.3mf, ESP32WalkieTalkie_Enclosure_Assembly.3mf]
